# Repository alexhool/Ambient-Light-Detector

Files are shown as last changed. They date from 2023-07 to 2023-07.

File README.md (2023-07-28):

# Ambient Light Detector
Measure ambient light utilizing opto-sensing. (My internship project at **[OSI Optoelectronics](https://www.osioptoelectronics.com/)**.)

## How to Run:
1. Download the source code either from the zip or by cloning the repository
2. Navigate into the "Ambient Light Detector" folder
3. Upload [light_serial.ino](https://github.com/alexhool/Ambient-Light-Detector/blob/master/Ambient%20Light%20Detector/light_serial/light_serial.ino) to an Arduino IDE compatible board
   - Located in the "light_serial" folder
4. Either run the executable [Ambient Light Detector.exe](https://github.com/alexhool/Ambient-Light-Detector/blob/master/Ambient%20Light%20Detector/Ambient%20Light%20Detector.exe) or skip to step 5
5. Navigate into the "light_gui" folder
6. Install required dependencies from "requirements.txt"
   - Prerequisite: [Python 3.8+](https://www.python.org/downloads/)
   - Using pip: `pip install -r "requirements.txt"` 
7. Run [light_gui.py](https://github.com/alexhool/Ambient-Light-Detector/blob/master/Ambient%20Light%20Detector/light_gui/light_gui.py)

## Design Files:
- STEP files are included for 3D printing or basic CAD
  - Files were designed specifically for the parts listed 
- For High Quality CAD models use [assembly.f3z](https://github.com/alexhool/Ambient-Light-Detector/blob/master/Design%20Files/assembly.f3z)
  - The *.f3z file extension is a Fusion 360 Zip Archive which contains every part file as a *.f3d file

## Parts List:
- Arduino Nano*
- OSD60-0*
- OPA341*
- 12-Pin SMT Breakout PCB*
- 5mm LED
- 100 Ω Resistor†
- 50 kΩ Resistor†
- 15 pF Capacitor†

*\*Similar component types can be used (compatibility with 3D models not ensured)*\
†*Values can be ±25% of those specified*

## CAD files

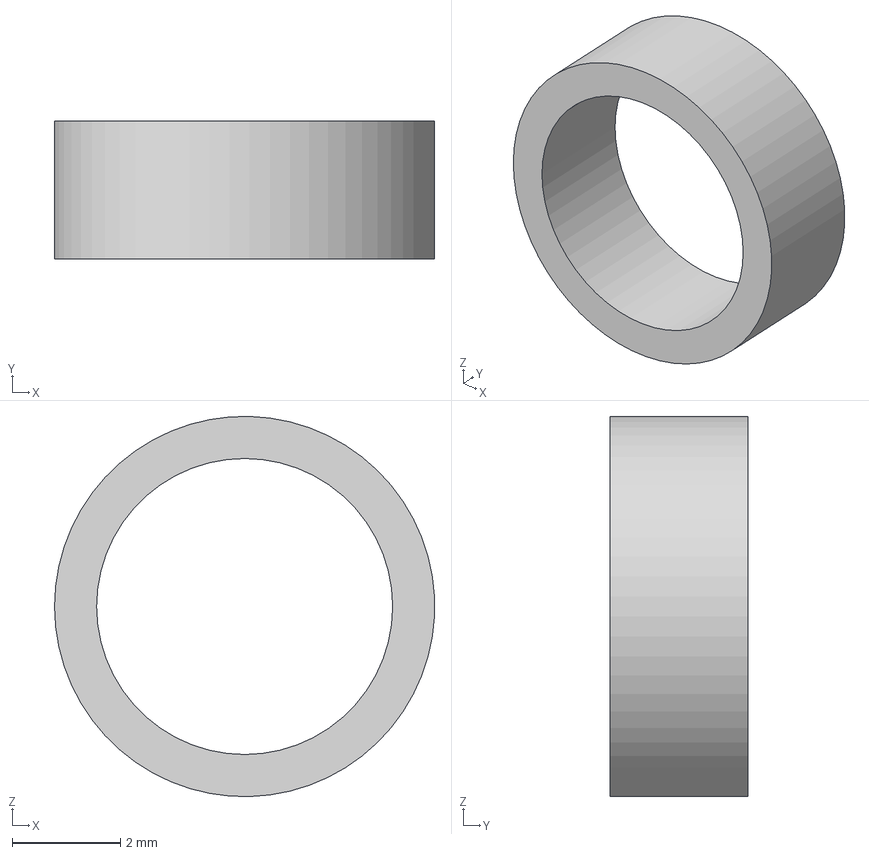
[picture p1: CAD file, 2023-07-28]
Design Files/led spacer.step
7.01 x 2.54 x 7.01 mm

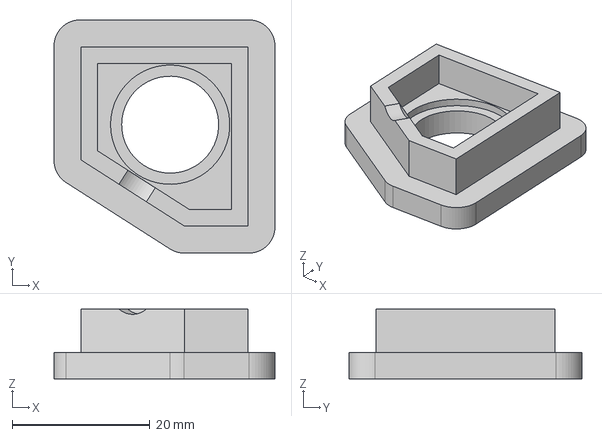
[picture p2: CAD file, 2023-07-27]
Design Files/lid.step
32.1 x 33.9 x 10.2 mm

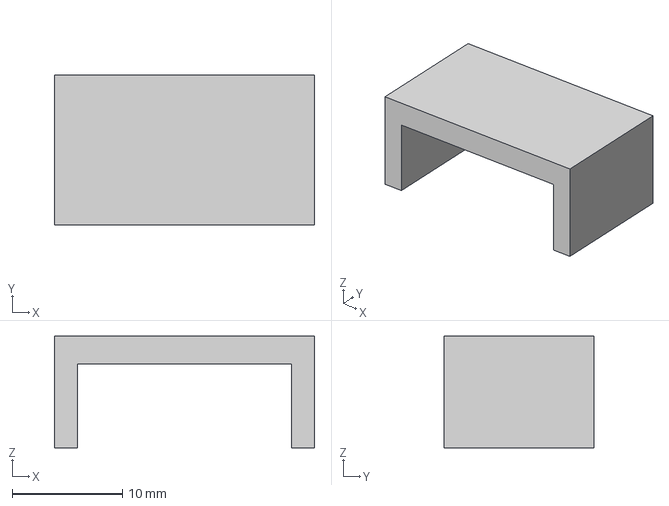
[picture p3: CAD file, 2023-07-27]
Design Files/case spacer.step
23.6 x 13.6 x 10.2 mm

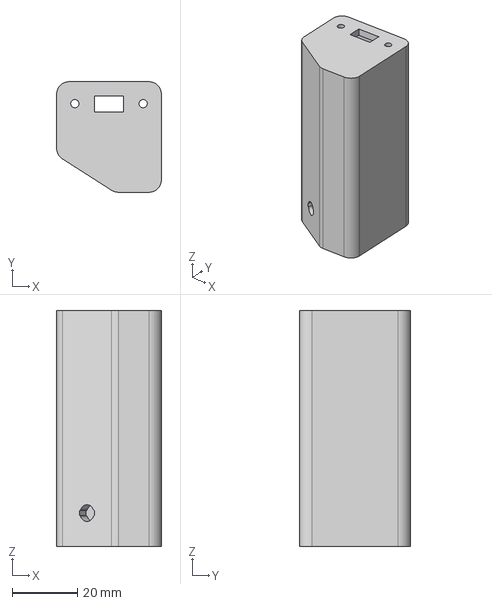
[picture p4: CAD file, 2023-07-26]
Design Files/holder.step
32.1 x 33.9 x 72.4 mm

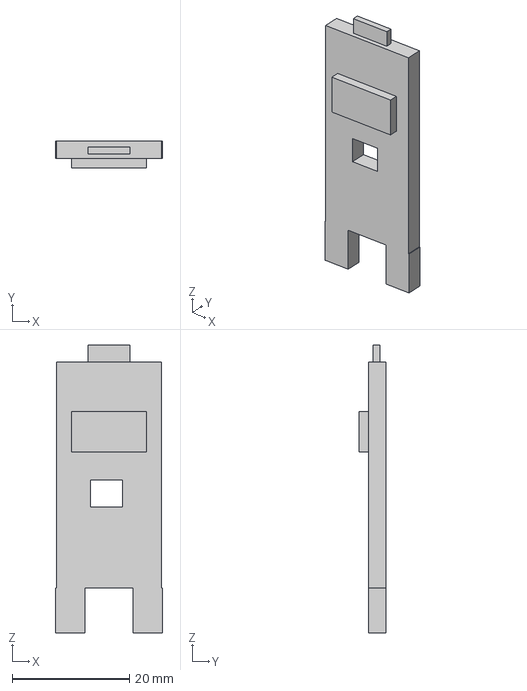
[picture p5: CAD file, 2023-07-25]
Design Files/case cover.step
18.2 x 4.66 x 49.1 mm

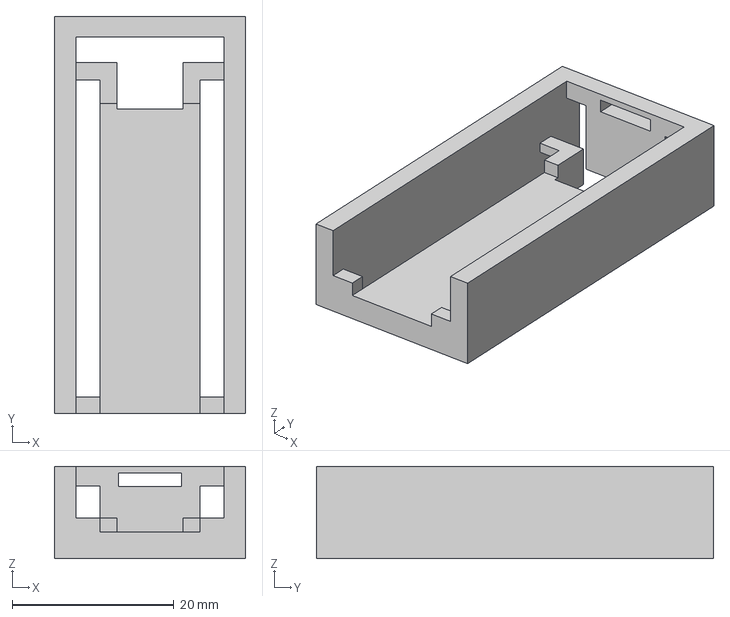
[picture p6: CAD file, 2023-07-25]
Design Files/case.step
23.6 x 49.1 x 11.4 mm

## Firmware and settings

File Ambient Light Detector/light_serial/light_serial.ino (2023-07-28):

bool ledOn = false;
bool nightOn = false;
bool stateOn = false;

void setup() {
  Serial.begin(9600);
  pinMode(2, OUTPUT);
  digitalWrite(2, LOW);
}

void loop() {
  int value = analogRead(A7);
  Serial.print(value);
  Serial.flush();
  Serial.print('|');
  Serial.flush();
  if (Serial.available() > 0) {
    int incomingByte = Serial.read();
    if (incomingByte == 'H') {
      ledOn = true;
    }
    if (incomingByte == 'L') {
      ledOn = false;
    }
    if (incomingByte == 'N') {
      nightOn = true;
    }
    if (incomingByte == 'D') {
      nightOn = false;
    }
  }
  if (ledOn) {
    if (value > 1018) {
      digitalWrite(2, HIGH);
      delayMicroseconds(11465);
    } else if (value < 45) {
      digitalWrite(2, LOW);
      delayMicroseconds(11465);
    } else {
      int delay = round((unsigned long) value * value / 91.0);
      digitalWrite(2, HIGH);
      delayMicroseconds(delay);
      digitalWrite(2, LOW);
      delayMicroseconds(11410 - delay); 
    }
  } else if (nightOn) {
    if (value >= 206) {
      stateOn = false;
      digitalWrite(2, LOW);
    } else if (value <= 103) {
      stateOn = true;
      digitalWrite(2, HIGH);
    } else {
      if (stateOn) {
        digitalWrite(2, HIGH);
      } else {
        digitalWrite(2, LOW);
      }
    }
    delayMicroseconds(11463);
  } else {
    digitalWrite(2, LOW);
    delayMicroseconds(11465);
  }
}

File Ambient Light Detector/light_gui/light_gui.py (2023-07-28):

# Standard imports
import os
import time
import tkinter as tk
from contextlib import suppress

# Non-standard imports as found in requirements.txt
import psutil
import serial
from matplotlib.backends.backend_tkagg import FigureCanvasTkAgg
from matplotlib.figure import Figure


class LightGui:
    def __init__(self, ser):
        # Initialize the serial connection
        self.ser = ser

        # Initialize the Tkinter GUI
        self.root = tk.Tk()

        # Initialize the plot
        self.fig = Figure(figsize=(4, 6), facecolor="#fdefc3")
        self.ax = self.fig.add_subplot(1, 1, 1)
        self.rect = self.ax.bar(
            x="Brightness",
            height=0,
            color="#fcd768",
            edgecolor="#000000",
            linewidth=0.7,
            width=2,
            align="center",
        )
        self.textVolt = self.ax.text(0, 0, "", ha="center", va="bottom", size=11)

        # Initialize the plot to the Tkinter widget
        self.canvas = FigureCanvasTkAgg(self.fig, self.root)

        # Initialize Serial Connection label
        self.labelSer = tk.Label(
            self.root,
            text="Serial Connection",
            font=("DejaVu Sans", 15),
            bg="#fdefc3",
            wraplength=110,
            justify="center",
        )

        # Initialize the Serial On button
        self.onSer = tk.Button(
            self.root,
            text="On",
            width=10,
            height=1,
            font=("DejaVu Sans", 9),
            bg="#D3D3D3",
            state="disabled",
            command=self.serial_on,
        )

        # Initialize the Serial Off button
        self.offSer = tk.Button(
            self.root,
            text="Off",
            width=10,
            height=1,
            font=("DejaVu Sans", 9),
            bg="#fefdf9",
            state="normal",
            command=self.serial_off,
        )

        # Initialize LED Visualizer label
        self.labelLED = tk.Label(
            self.root,
            text="LED Visualizer",
            font=("DejaVu Sans", 15),
            bg="#fdefc3",
            wraplength=100,
            justify="center",
        )

        # Initialize the LED On button
        self.onLED = tk.Button(
            self.root,
            text="On",
            width=10,
            height=1,
            font=("DejaVu Sans", 9),
            bg="#fefdf9",
            state="normal",
            command=self.led_on,
        )

        # Initialize the LED Off button
        self.offLED = tk.Button(
            self.root,
            text="Off",
            width=10,
            height=1,
            font=("DejaVu Sans", 9),
            bg="#D3D3D3",
            state="disabled",
            command=self.led_off,
        )

        # Initialize the Night LED label
        self.labelNightLED = tk.Label(
            self.root,
            text="LED\nNight Light",
            font=("DejaVu Sans", 15),
            bg="#fdefc3",
            wraplength=100,
            justify="center",
        )

        # Initialize the Night LED On button
        self.onNightLED = tk.Button(
            self.root,
            text="On",
            width=10,
            height=1,
            font=("DejaVu Sans", 9),
            bg="#fefdf9",
            state="normal",
            command=self.night_on,
        )

        # Initialize the Night LED Off button
        self.offNightLED = tk.Button(
            self.root,
            text="Off",
            width=10,
            height=1,
            font=("DejaVu Sans", 9),
            bg="#D3D3D3",
            state="disabled",
            command=self.night_off,
        )

        # Initialize the Lux label
        self.labelLux = tk.Label(
            self.root,
            text="Incident Light Value",
            font=("DejaVu Sans", 15),
            bg="#fdefc3",
            wraplength=100,
            justify="center",
        )

        # Initialize the Lux value label
        self.textLux = tk.Label(
            self.root,
            width=11,
            height=1,
            font=("DejaVu Sans", 13),
            bg="#fefdf9",
            borderwidth=1,
            relief="solid",
            anchor=tk.CENTER,
        )

        # Initialize the quit button
        self.quitB = tk.Button(
            self.root,
            text="QUIT",
            width=10,
            height=2,
            font=("DejaVu Sans", 9),
            bg="#fefdf9",
            activebackground="#de282c",
            activeforeground="#fefdf9",
            command=self.exit_gui,
        )

    def create_gui(self):
        # Set up the Tkinter GUI
        self.root.title("Ambient Light Graph")
        self.root.iconbitmap("light-bulb.ico")
        self.root.geometry("545x621")
        self.root.resizable(False, False)
        self.root.config(bg="#fdefc3")

        # Set up the plot
        self.fig.subplots_adjust(top=0.865, bottom=0.1, left=0.215, right=0.85, hspace=0.2, wspace=0.2)
        self.ax.set_facecolor("#fefdf9")
        self.ax.tick_params(axis="x", bottom=False, labelsize=14, pad=10)
        self.ax.tick_params(axis="y", left=True, labelsize=12, pad=2)

        # Add the plot to the Tkinter widget
        self.canvas.get_tk_widget().config(bg="#000000")
        self.canvas.get_tk_widget().grid(column=0, row=0, rowspan=2, sticky=tk.N, padx=10, pady=8, ipadx=5, ipady=2)

        # Add Serial Connection label
        self.labelSer.grid(column=1, row=0, rowspan=2, padx=0, pady=26, sticky=tk.N)

        # Add the Serial On button
        self.onSer.grid(column=1, row=0, rowspan=2, padx=14, pady=84, sticky=tk.N)

        # Add the Serial Off button
        self.offSer.grid(column=1, row=0, rowspan=2, padx=14, pady=111, sticky=tk.N)

        # Add LED Visualizer label
        self.labelLED.grid(column=1, row=1, rowspan=4, padx=0, pady=156, sticky=tk.N)

        # Add the LED On button
        self.onLED.grid(column=1, row=1, rowspan=1, padx=14, pady=214, sticky=tk.N)

        # Add the LED Off button
        self.offLED.grid(column=1, row=1, rowspan=1, padx=14, pady=241, sticky=tk.N)

        # Add the Night LED label
        self.labelNightLED.grid(column=1, row=1, rowspan=1, padx=0, pady=286, sticky=tk.N)

        # Add the Night LED On button
        self.onNightLED.grid(column=1, row=1, rowspan=1, padx=14, pady=344, sticky=tk.N)

        # Add the Night LED Off button
        self.offNightLED.grid(column=1, row=1, rowspan=1, padx=14, pady=371, sticky=tk.N)

        # Add the Lux label
        self.labelLux.grid(column=1, row=1, padx=0, pady=416, sticky=tk.N)

        # Add the Lux value label
        self.textLux.grid(column=1, row=1, padx=1, pady=474, ipady=16, sticky=tk.N)

        # Add the quit button
        self.quitB.grid(column=1, row=1, padx=13, pady=564, sticky=tk.N)
        self.root.protocol("WM_DELETE_WINDOW", self.exit_gui)
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

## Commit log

2023-06-08 led finished
2023-06-09 send voltage over serial
2023-06-12 led control
2023-06-13 led visualizer works
2023-06-15 square ramp for led
2023-06-20 corrected voltage calc
2023-06-20 fine-tuned voltage calc
2023-06-22 update voltage calc
2023-06-23 voltage calc
2023-06-23 voltage calc w/ op amp
2023-06-23 voltage calc accuracy
2023-07-10 best voltage calc
2023-07-10 adjusted led brightness scale to tia max output
2023-07-12 fixed visible led flickering at high voltages
2023-07-13 synchronized delays & created absolutes for led
2023-07-13 changed led pin
2023-07-17 added design files
    [OSD60-0_v9.f3d, assembly_v33.f3d, case spacer_v8.f3d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]
2023-07-17 changed design file format
    [OSD60-0_v9.f3d, assembly_v33.f3d, case spacer_v8.f3d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]
2023-07-17 include stls
    [case spacer.stl, case.stl, led spacer.stl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]
2023-07-18 widen led hole
2023-07-18 Remove ignored files
    [case spacer.stl, case.stl, led spacer.stl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]
2023-07-19 model updates
    [case cover.stl, case.stl]
2023-07-21 improve led fit
    [led spacer.stl]
2023-07-24 update 3d models
    [case cover.stl, case spacer.stl, case.stl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]
2023-07-25 added higher res design files
    [case cover.step, case cover.stl, case spacer.step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]
2023-07-25 calibrated lux calculation
2023-07-26 added night led to arduino
2023-07-27 final 3d models
    [case spacer.step, led spacer.step, lid.step]
